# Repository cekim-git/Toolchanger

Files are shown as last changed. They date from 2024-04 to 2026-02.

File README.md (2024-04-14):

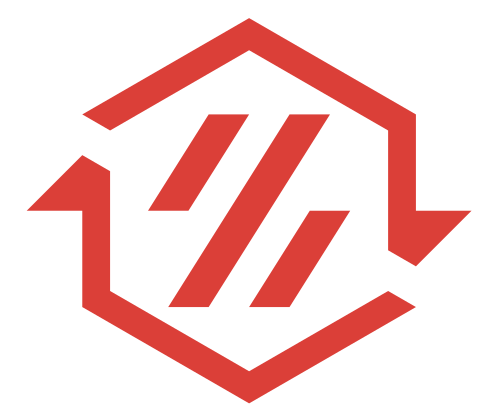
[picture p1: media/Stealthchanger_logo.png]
#  StealthChanger
**Tool changing system for Vorons and other front mount printer motion systems.**

## Introduction

Unlike the name suggests we support more then just stealthburner.

Due to difficulties with heat insert and aligning of bearings and mounts we wanted to try a more simplistic design based on bushings and pins.

This is a very light design, requiring less parts and as such is cheaper and easier to build.  Input shaper tests have shown it to be as rigid if not more than current Tapchanger.

All parts are easily replaceable without reprinting if wear happens, life of the bushings and pins are still being tested.

## Tool compatability
Currently we support the standard Stealth Burner, Dragon Burner, and Rapid Burner.  There are plans in place to add the Mini Stealth Burner, XOL, and Archetype.

## Documentation and Info

Please use our [wiki](../../wiki) for more information and documentation.

- [Bill of Materials](../../wiki/Bill-of-Materials)
- [Printing](../../wiki/Printing)
- [Assembling](../../wiki/Assembling)
- [Installation](../../wiki/Installation)
- [Configuration](../../wiki/Configuration)
- [Docks](../../wiki/Docks)
- [Slicers](../../wiki/Slicers)
- [Support and FAQs](../../wiki/Support-and-FAQs)
- [Contributing](../../wiki/Contributing)
- [Contributors & Credits](../../wiki/Contributors-and-Credits)

## Preview
### Printed Parts (Dragonburner) by BT123


### Important! - Check for clear Hex's (Dragonburner) by BT123
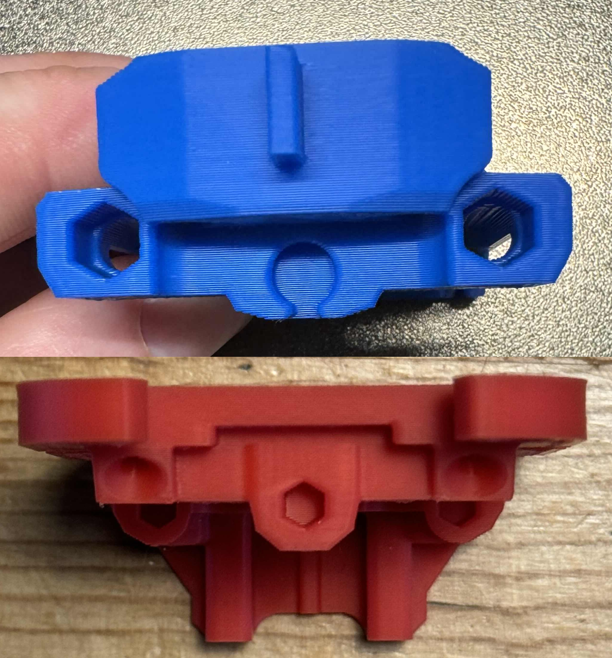
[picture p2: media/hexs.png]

### Assembled Shuttle and Backplate by BT123

### Motion (Stealthburner) by TheSin-

### Docking (Stealthburner) by fiferboy


Originally based on Viesturz's [Tapchanger](https://github.com/viesturz/tapchanger)

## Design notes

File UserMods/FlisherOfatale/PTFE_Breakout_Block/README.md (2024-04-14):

# PTFE Breakout Block

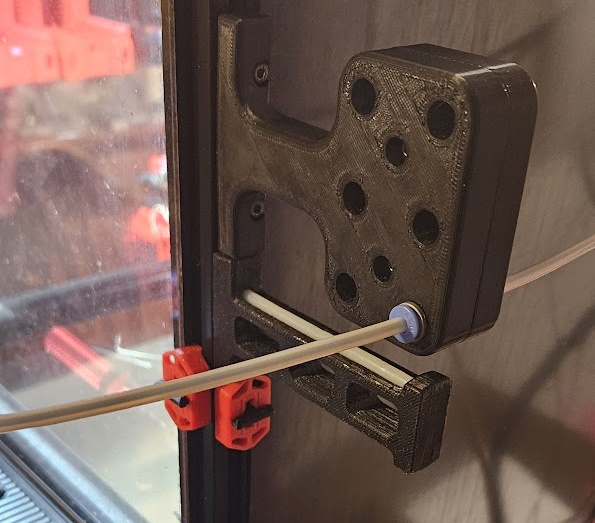
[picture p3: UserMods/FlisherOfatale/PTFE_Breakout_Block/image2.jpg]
PTFE Breakout Block


## What is it?
I designed the Breakout Block with the following idea in mind:
* Similar "lenght" than the stock Voron Spool Holder so it maintain existing clearance for people using the original setup
* Provide some constrain to the PTFE so it doesn't king when using 3mm innder diameter
* use ECAS because they are practical for this purpose
* Optional, seconary part that serve as a breakout block, allowing to "detach" easily both side of the block to decouple the toolhead and the spool holder when doing printer maintenance

## Special Notes
The design is probably not perfect but it was good enought for me at this point.

## Files
* [Main part v3.1](Flisher-PTFE_Breakout_Block_Main-v3.1.stl)
* [Secondary Part v3.1](Flisher-PTFE_Breakout_Block_Secondary-v3.1.stl)
* [Step File](Flisher-Toolchanger-PTFE-Holder-v3.1.STEP)

## BOM
* 2x M3 T-Nuts or Roll-in Nuts
* 2x M3x12 SHCS Screws 
* 1x ECAS Connector per Lane you want activate

If using both parts
* 2x M3x16 SHCS Screws (Voron Sandard)
* 2x M3 heat insert (Voron Sandard)
* Additional 1x ECAS Connector per Lane you want activate (ie: 12 totals if using 6 toolheads)

## Instructions
### Main Part
* Validate that your PTFE can go trought easily, if not, you might have to deburr rthe side facing the bed.
* Install the ECAS connectors
* Screw to the back of the printer using M3 T-Nuts and M3x12 SHCS Screws

You can stop here if you only wanted something to constrain the filament path and use it as a passtrought

### Secondary part
* Validate that your PTFE can go trought easily, if not, you might have to deburr rthe side facing the bed.
* Install the ECAS connectors
* Install the 2 heats inserts (on the same side than the ECAS connector)
* Install on the main block by using 2x M3x16 SHCS Screws
* Push the PTFE coming from the main part as it can get 2mm inside 
* Attach the PTFE from the printer side
  
You now have a setup you can decouple by pulling the filament back to the spool holders and unscrewing the block.

### Additional Pictures
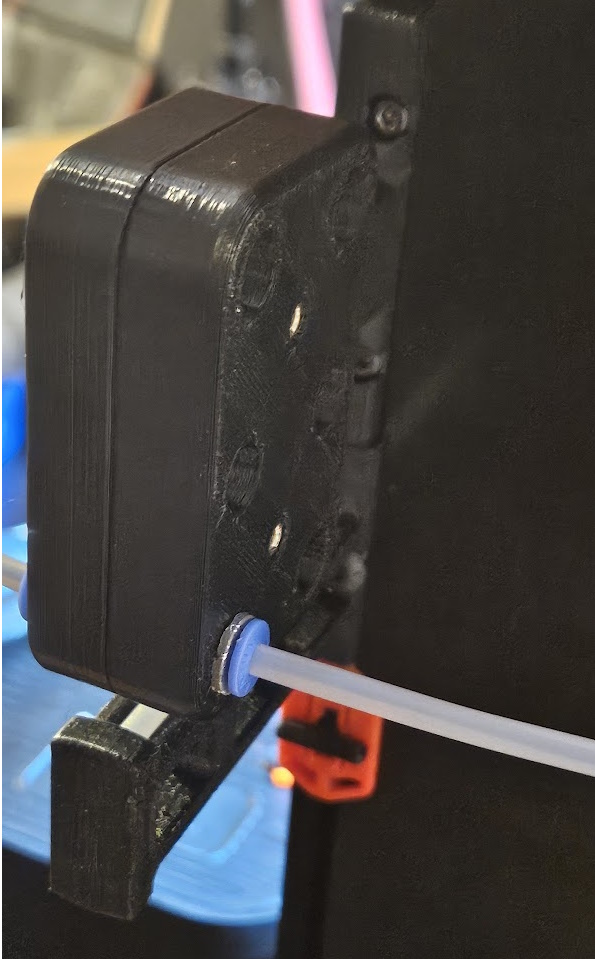
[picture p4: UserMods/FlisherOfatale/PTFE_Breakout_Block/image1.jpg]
Secondary Partg


## Changelog
* V3.1 2024-03-24 - Initial Release, each parts are 12mm wide

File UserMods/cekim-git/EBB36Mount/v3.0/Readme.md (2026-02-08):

## Dragon Burner EBB36 mount for the Orbiter2.x extruder
This mount for DragonBurner provides a mount for the EBB36 that attaches to the rear of the Orbiter2.x and provides a pivoting strain-relief tower intended to be used with a 1mm piano wire.

## Design Goals:
- As with prior versions, provided centered EBB36 mount (offset from extruder motor) and provide clearance for optTap sensor
- Move cable mount to pivoting tower as close to the front as possible to line up with the filament tube
- Optional heatset in the wire strain-relief tower to permit bung-screw to clamp the piano wire
- Does not integrate with the filament sensor, optimizing for umbilical/PTFE alignment/movement

## BOM:
- 3x m3 (x4x5) heatset-inserts in EBB36 mount holes 
- 2 m3x8 SHCS or BHCS (EBB36 mount)
- 1 m3x20 SHCS (pivot mount)
- (optional) 1x m3x4x5 heatset-insert for wire-tower clamp
- (optional) 1x m3x4 cup-point set-screw (bung screw)

## Printing:
- I print this standing upright with supports on overhanging elements
- ABS with shrinkage compensation - ensure you are printing with accurate dimensionality of finished part

## Installation:
- Install heatsets to EBB36 mounting face.
- Remove the 2 m3x16 SHCS holding the stepper motor of the Orbiter2.0 to the gearbox taking care to keep the gearbox assembled while the screws are removed.
- Replace stock gear-box screws with m3x25 screws
- While keeping the stepper motor, optional sensor and gearbox assembly together, slide the rear of the stepper into the mount's cup that is sized to fit around it. 
- Line up the screw-holes on the fingers with the Orbiter's stepper motor fastener holes.
- While pressing this entire assembly together, thread in the m3x25 screws.  You are simultaneously fastening the Orbiter2.x stepper to its gear-box and self-tapping the 3mm ABS holes on the mounting bracket, so keep them pressed together the entire time.
- Install EBB36 with 2 m3x8 SHCS or BHCS to the rear.
- If using the "piano-wire" hole, you may want to insert your 1mm wire prior to assembly to clear out any printing artifacts.  It is a ~18-20mm deep hole.
- If using the clamping wire-tower, press the heat-set insert into the tower
- Fasten the piano wire with teh m3x4 bung/set screw
- Wire as needed.





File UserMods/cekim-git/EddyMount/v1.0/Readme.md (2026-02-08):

## Eddy Coil Mount in a DragonBurner Tool-head
This design places the EddyCoil PCB in the spacer of the Dragon Burner toolhead

Dragonburner orignal design chirpy2605 here https://github.com/chirpy2605/voron

## Design Goals:
- Integrate EddyCoil into dockable toolhead

This uses "standard" DragaonBurner cowls

## BOM:
- (optional) aluminum tape (insullation)
- (optional) catridge PT1000 sensor

## Printing:
- Print in normal orientation for spacer
- Use supports for inner segments of both the spacer and front cover

## Installation:
- Insert PT1000
- Remove Eddy from its housing (carefully)
- Insert Eddy into printed spacer
- Place front cover
- Install spacer as normal from here




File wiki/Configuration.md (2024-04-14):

Toolchangers start with number 0, and count up. So for all the configs, make sure you change all sections. IE, in your T1 config, make sure its extruder1, fan1, etc. See the examples.  **NOTE: The only except to this rule is T0 extruder has no number.**

1. [Toolhead Configuration](#toolheads-configuration)
2. [CANbus](#canbus)
3. [Offsets](#offsets)

## Toolheads Configuration

Please see the repo files for more info on these. [Configuration Files Repo](https://github.com/DraftShift/StealthChanger/blob/main/Klipper)
[testing](/blob/main/Klipper)

You need to add the info in printer.cfg from the repo to your your printer.cfg
You need to have a separate toolhead config for each toolhead, then link those in your printer.cfg, as well as removing/moving the current extruder/hotend config from your printer.cfg file. See the examples in the repo for more information and a starting place. You will have to edit them with your own values.

## CANbus

[Esoterical CANbus](https://github.com/Esoterical/voron_canbus) this is a pretty definitive guide for canbus implementation on klipper.

**Example CANbus layout**

Example CANbus Layout

## Offsets

There are 2 places to set offsets in your toolhead config files. There is gcode_(x/y/z)_offset in the [tool] section, and (x/y/z)_offset in the [tool_probe] section. These do different things. The ones in the [tool] section are always relative to a specific tool. IE, if you homed with T0, then the gcode offsets are relative to T0. When you do multi-material prints, you will have to choose 1 tool to always do the homing, even if you don't use it, because all the other offsets need to be set against it. The [tool_probe] offset is only ever applied when homing with that tool. The gcode offsets are applied when changing a tool.

You should set all the [tool_probe] offsets as well though. If you are only using a single tool, you can home with that tool, and it will use the offset in the [tool_probe] section. You won't need to home with your primary tool first then before you start a print. 

To try and further clarify. Lets say you have 3 tools, T0, T1, and T2. We will say that T0 is your "primary" tool. Setup the probe z_offset like you would any other printer. Make sure the offset is set in z_offset (IE, make sure when you home and go to Z0, the nozzle is actually in that spot). Its location in x/y/z is always going to be 0 in relation to the other tools. So after T0 is homed, T1 and T2 (may) need to have their gcode_(x/y/z)_offset changed so they match the location that the primary tool actually is. There are 2 main ways of doing this. You can use a test print to print layers on top of or next to each other (something like this: [Nozzle Alignment Assist](https://www.printables.com/model/109267-nozzle-alignment-assist)) or you can use a camera (something like [kTAMV Klipper Tool Alignment](https://github.com/TypQxQ/kTAMV) or [IDEX Nozzle Calibration Tool](https://github.com/Life0fBrian/Brians-IDEX-Nozzle-Calibration-tool)).

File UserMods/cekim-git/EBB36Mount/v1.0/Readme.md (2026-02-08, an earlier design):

## Dragon Burner EBB36 mount for the Orbiter2.0 extruder
This mount for DragonBurner provides a mount for the EBB36 that attaches to the rear of the Orbiter2.0. 

Dragonburner orignal design chirpy2605 here https://github.com/chirpy2605/voron

Traxman25's EBB36 mount takes a different approach and can be found here:
https://github.com/cekim-git/Toolchanger/tree/main/UserMods/traxman25/Dragonburner_EBB36_SC_Mount

## Design Goals:
- Keep the Orbiter 2.0 on the original/shorter exrtuder block, flush with the top of the cowl.
- Provide a CAN cable stress-relief tower with zip-tie holes that is shifted to be in-line with the filament tube for cable harness alignment.
- Provide clearance for the opto-tap PCB without adding over-all height or extending rearward (the EBB36 and OptoTap will be roughly in-line with eachother).
- Remove the need for stand-offs and potentially add rigidity by augmenting the attachment screws with design features fit to the outside of the Orbiter2 stepper motor.
- Support the optional Orbiter2.0 filament sensor via the mount with shorter fingers.
- Provide hole on cable stress-relief tower to insert 1mm "piano-wire" to support the umbilical

This uses "standard" DragaonBurner cowls - though it is specifically fit for Traxman25's numbered cowls for StealthChanger, it will also fit on a standard cowl.  It also works the V1 back-plate for StealthChanger/DragonBurner and OptoTap.

## BOM:
- 2 m3 (x4x5) heatset-inserts mounted from the opposite side as the EBB36 
- 2 m3x8 BHCS (EBB36 mount)
- (no filament sensor) 2 m3x20 SHCS to replace the Orbiter's stock screws and provide more thread purchase in the ABS.
- (filament sensor) 2 m3x25 SHCS to replace the Orbiter's stock screws

## Printing:
- I print this standing upright as it sits in the machine with organic/tree supports painted on to the most obvious overhangs.
- I use ABS with no adjustmnet for shrinkage from the design files as provided.

## Installation:
- Install heatsets to side opposite the EBB36 mounting face.  Ensure they are straight and the screw-path clear of overmelt after installation
- Remove the 2 m3x16 SHCS holding the stepper motor of the Orbiter2.0 to the gearbox taking care to keep the gearbox assembled while the screws are removed.
- Replace stock gear-box screws with m3x20 screws (or m3x25 if attaching the filament sensor).
- (optional) install the filament sensor to the Orbiter2.0.
- While keeping the stepper motor, optional sensor and gearbox assembly together, slide the rear of the stepper into the mount's cup that is sized to fit around it. 
- Line up the screw-holes on the fingers with the Orbiter's stepper motor fastener holes.
- While pressing this entire assembly together, thread in the m3x20 (or m3x25) screws.  You are simultaneously fastening the Orbiter2.0 stepper to its gear-box and self-tapping the 3mm ABS holes on the mounting bracket, so keep them pressed together the entire time.
- Install EBB36 with 2 m3x8 BHCS to the rear.
- If using the "piano-wire" hole, you may want to insert your 1mm wire prior to assembly to clear out any printing artifacts.  It is a 20mm deep hole.
- Wire as needed.





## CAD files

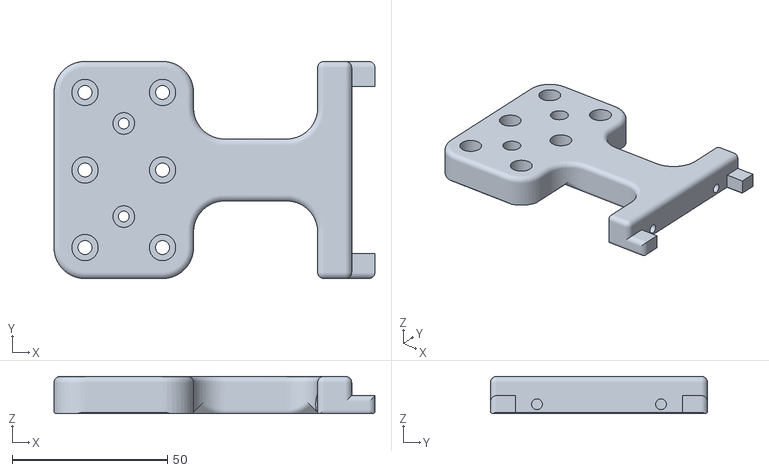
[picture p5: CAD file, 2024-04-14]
UserMods/FlisherOfatale/PTFE_Breakout_Block/Flisher-PTFE_Breakout_Block_Main-v3.1.stl
103.5 x 70.0 x 12.0

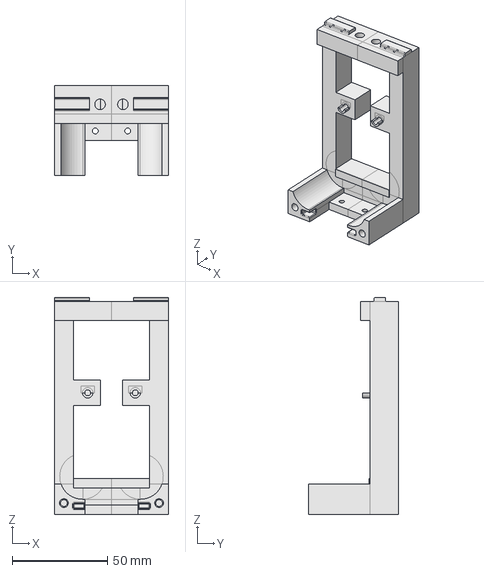
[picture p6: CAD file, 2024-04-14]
UserMods/cekim/DB_Dock/v0/DB_Dock.step
60.0 x 47.5 x 114.0 mm

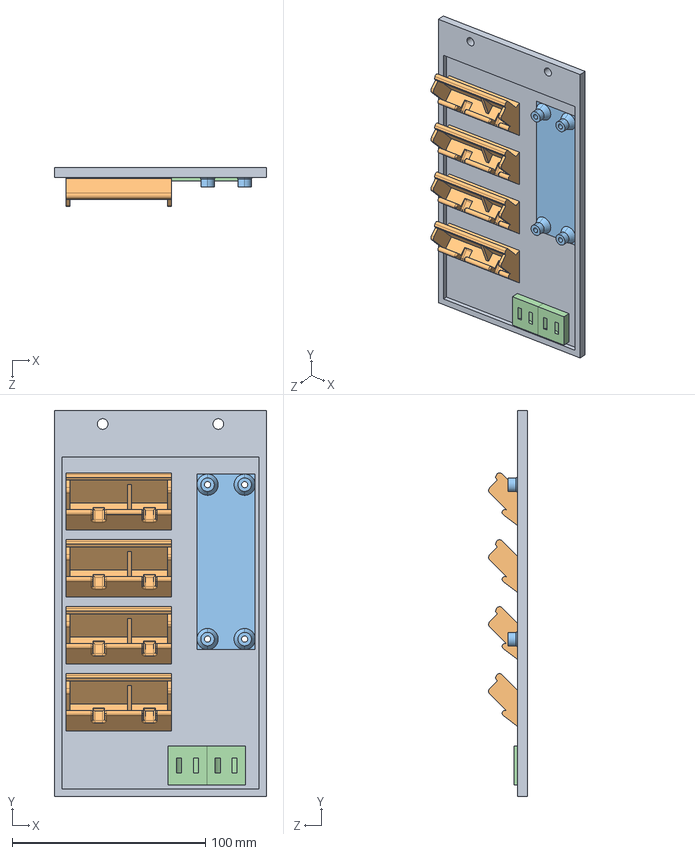
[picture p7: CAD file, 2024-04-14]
UserMods/FlisherOfatale/Temporary_Backplate/Flisher-Temporary_Backplate-V2.STEP
110.0 x 200.0 x 20.1 mm
Flisher-Backplate-v2-Naked
Stealchanger-Wago-5-3-Custom x 4
Stealchanger-BTT-U2C-SLDPRT
ZipTie-2020notch x 2

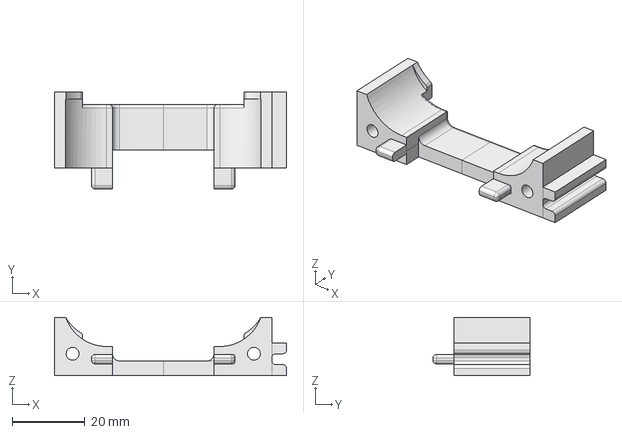
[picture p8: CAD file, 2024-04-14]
UserMods/cekim/DB_Dock/v0/DB_Dock_RearFemale.step
64.0 x 26.8 x 16.0 mm

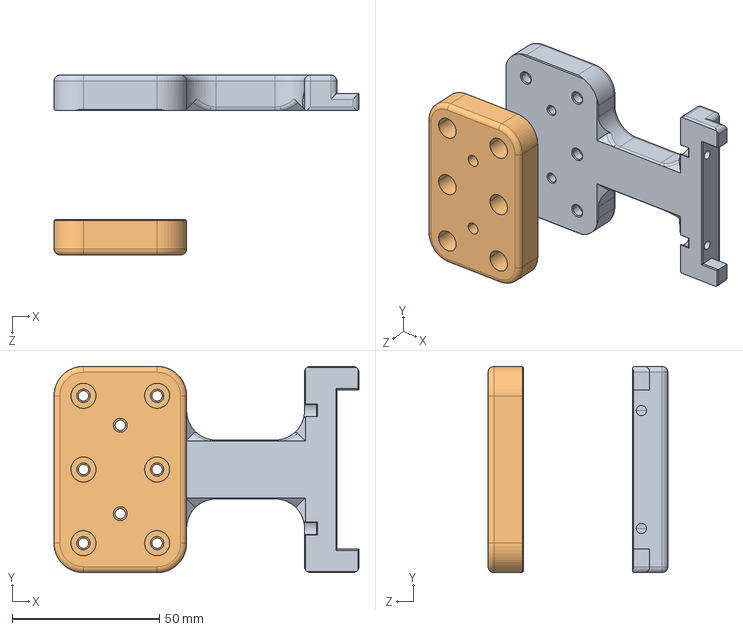
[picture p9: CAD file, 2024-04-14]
UserMods/FlisherOfatale/PTFE_Breakout_Block/Flisher-Toolchanger-PTFE-Holder-v3.1.STEP
103.5 x 70.0 x 61.0 mm

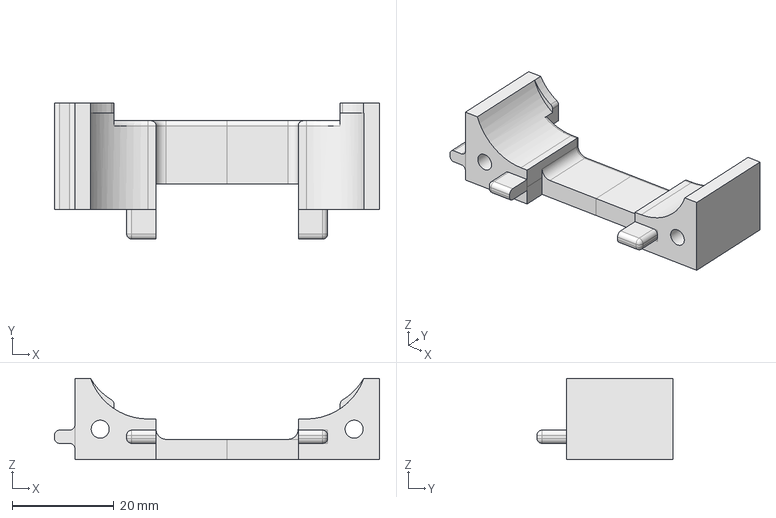
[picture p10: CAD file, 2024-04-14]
UserMods/cekim/DB_Dock/v0/DB_Dock_RearMale.step
64.0 x 26.8 x 16.0 mm

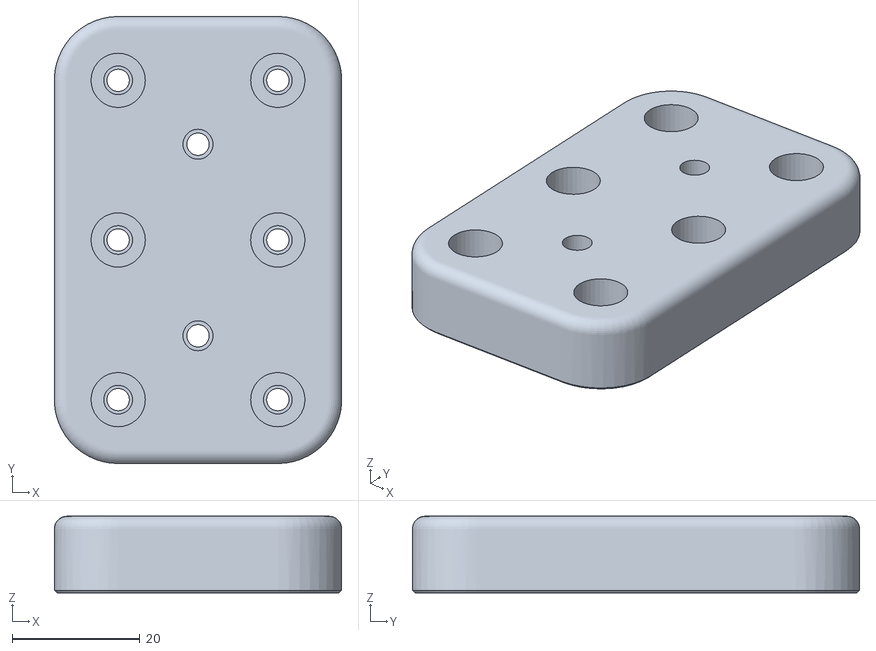
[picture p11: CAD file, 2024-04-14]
UserMods/FlisherOfatale/PTFE_Breakout_Block/Flisher-PTFE_Breakout_Block_Secondary-v3.1.stl
45.0 x 70.0 x 12.0

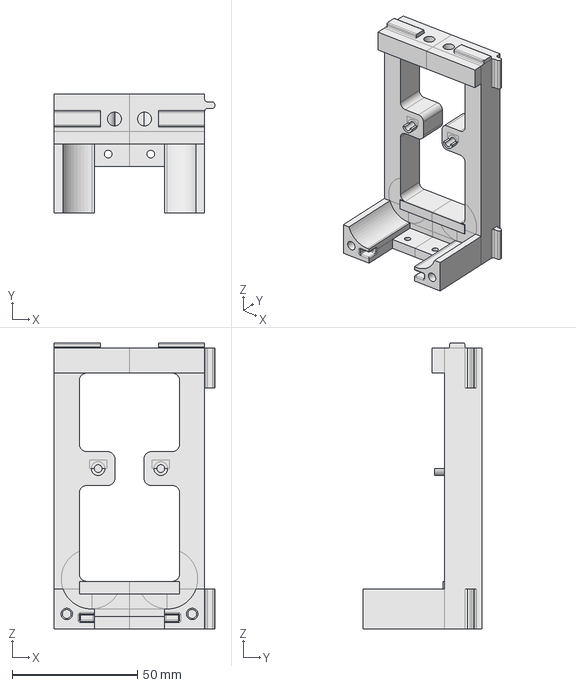
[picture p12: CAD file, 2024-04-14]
UserMods/cekim/DB_Dock/v0/DB_DockMale.step
64.0 x 47.5 x 114.0 mm

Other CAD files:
UserMods/cekim/DB_Dock/v0/DB_DockFemale.step
UserMods/FlisherOfatale/Temporary_Backplate/Flisher-Temporary_Backplate-V2.STL

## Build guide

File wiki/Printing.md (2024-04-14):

1. [Parts](#parts)
2. [Settings](#settings)
3. [Orientation](#orientation)

## Parts

**NOTE: The Dragonburner dock in the Tapchanger repo uses a custom cowl that is not compatible with or supported by Stealthchanger. Until a dock that is compatible with the original Dragonburner cowl is released, you must use the [custom cowl by OstroMa](https://github.com/DraftShift/StealthChanger/blob/main/UserMods/OstroMa/DB_Cowl_v8_with_TapChanger_Dock_Hooks.stl). We always recommend to use the original cowls when possible.**

Coming Soon

## Settings

All print settings are the same as [Voron Standards](https://docs.vorondesign.com/sourcing.html#print-settings) or better.

## Orientation

Print orientation is flat on the parts back with supports enabled currently, we are working on models with integrated supports.

Print Orientation

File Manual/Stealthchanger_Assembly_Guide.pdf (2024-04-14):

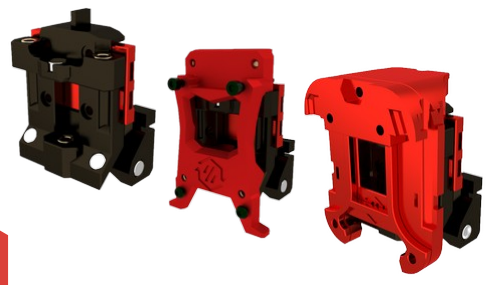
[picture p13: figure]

# STEALTHCHANGER V1 BUILD GUIDE

# Because you can never have too many tools

for any project.

# VERSION 2024-04-12

# DRAFTSHIFT DESIGN

PREFACE | GITHUB.COM/DRAFTSHIFT/STEALTHCHANGER

Before you begin on your journey, a word of caution.

In the comfort of your own home you are about to assemble a robot. This machine can maim, burn, and electrocute you if you are not careful. Please do not become the first STEALTHCHANGER fatality. There is no special Reddit flair for that.

Please, read the entire manual before you start assembly. As you begin wrenching, please check our Discord channels for any tips and questions that may halt your progress.

Most of all, good luck!

THE DRAFTSHIFT DESIGN TEAM

2

## TABLE OF CONTENTS

Introduction | 04
Hardware | 07
Shuttle | 08
Stealthburner | 11
Dragonburner | 14
Attaching to Carriage | 17
End Stop Options | 21
Next Steps | 22

3

## GITHUB.COM/DRAFTSHIFT/STEALTHCHANGER

## INTRODUCTION

PART PRINTING GUIDELINES

The Voron Team has provided the following print guidelines for you to follow in order to have the best chance at success with your parts. The StealthChanger Team recommends to follow the same standards. There are often questions about substituting materials or changing printing standards, but we recommend you follow these:

3D PRINTING PROCESS
Fused Deposition Modelling (FDM)

MATERIAL
ABS

LAYER HEIGHT
Recommended: 0.2mm

EXTRUSION WIDTH
Recommended: Forced 0.4mm

INFILL TYPE
Grid, Gyroid, Honeycomb, Triangle or Cubic

INFILL PERCENTAGE
Recommended: 40%

WALL COUNT
Recommended: 4

SOLID TOP/BOTTOM LAYERS
Recommended: 5

4

## INTRODUCTION

FILE NAMING

By this time you should have already downloaded our STL files from the StealthChanger GitHub. You might have noticed that we have used the Voron naming convention for the files. This is how to use them.

PRIMARY COLOUR

Example part_x4.stl

These files will have nothing at the start of the filename.

ACCENT COLOUR

Example [a]_part.stl

We have added “[a]” to the front of any STL file that is intended to be printed with accent colour.

QUANTITY REQUIRED

Example [a]_part_x4.stl

If any file ends with “_x#”, that is telling you the quantity of that part required to build the machine.

HOW TO GET HELP

If you need assistance with your build, we are here to help. Head on over to our Discord group and post your questions. This is our primary medium to help STEALTHCHANGER Users and we have a great community that can help you out if you get stuck.

### https://discord.gg/jJs73c6vSc

5

## INTRODUCTION

REPORTING ISSUES

Should you find an issue in the documentation or have a suggestion for an improvement please consider opening an issue on GitHub (https://github.com/DraftShift/Stealthchanger/issues). When raising an issue please include the relevant page numbers and a short description; annotated screenshots are also very welcome. We periodically update the manual based on the feedback we get.

THIS IS JUST A REFERENCE

This manual is designed to be a simple reference manual. Building a StealthChanger can be a complex endeavour and for that reason we recommend downloading the CAD files off our Github repository if there are sections you need clarification on. It can be sometimes be easier to follow along when you have the whole assembly in front of you.

### https://github.com/DraftShift/StealthChanger

6

## HARDWARE REFERENCE

BUTTON HEAD CAP SCREW (BHCS) Metric fastener with a domed shape head and hex drive. Most commonly found in locations where M5 fasteners are used. ISO 7380-1 | SOCKET HEAD CAP SCREW (SHCS) Metric fastener with a cylindrical head and hex drive. The most common fastener used on the Voron. ISO 4762
FLAT HEAD COUNTERSUNK SCREW (FHCS) Metric fastener with a cone shaped head and a flat top. ISO 10642 | HEAT SET INSERT Heat inserts with a soldering tip so that they melt the plastic when installed. As the plastic cools, it solidifies around the knurls and ridges on the insert for excellent resistance to both torque and pull-out.
BUSHING/SLEEVE BEARING Brass cindered are the most common. They should be self lubricating and metal construction. | ROUNDED DOWEL PIN Steel rounded dowel pin, These are commonly using in furniture construction. Female threaded versions are optional.

MAGNET Metric round button neodymium magnet used on the Voron. N52 is highly recommended.

7

## SHUTTLE

INSERT BUSHINGS

Inspect the bushing hex holes, make sure they are 6mm between walls of the hex. Make sure the hex is well formed. This is an important step as it could cause misalignment later on.

Apply a small amount of epoxy or glue to the inside of the hex (be sparing as you do not want any inside the the bushing).

Push the bushing into the hex and let sit until the epoxy or glue dries.

NOTE: Wipe any excess away and make sure none goes inside the bushing.

NOTE: you may be able to friction fit the bushings to test before your affix them permanently.

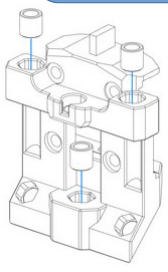
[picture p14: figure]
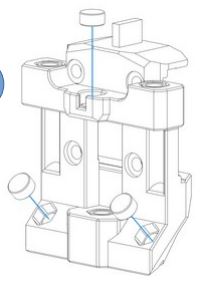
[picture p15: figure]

INSERT MAGNETS

Apply a small amount of epoxy or glue to the inside of the opening.

Push the magnet into the opening and let sit until the epoxy or glue dries.

NOTE: you may be able to fiction fit the magnets to test before your affix them permanently.

## 4 ID x 6 OD x 6mm Bushing

## 6x3mm Magnet

8

## SHUTTLE

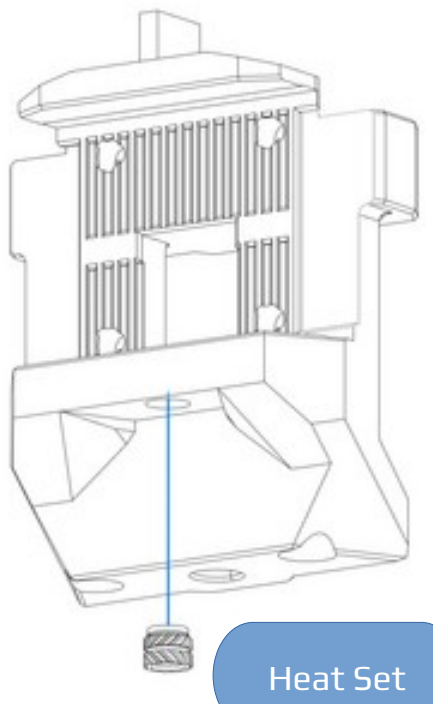
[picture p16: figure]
Heat Set

OPTIONAL INSERT HEAT SET

Optionally insert the end stop heat set. Only required if you are not using sensorless.

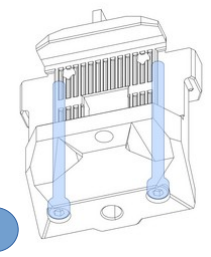
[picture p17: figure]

OPTIONAL SPINE SCREWS

Optionally screws can be inserted to add rigidity to the shuttle if your not happy with it’s stiffness

## M3x40mm SHCS

9

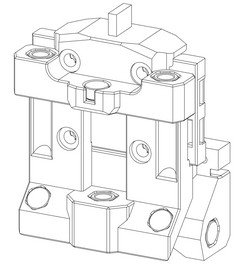
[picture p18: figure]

FINISHED SHUTTLE

This is the finished shuttle with options shuttle keeper (later in this manual) and the optional Hall Effect end stop attachment (later in this manual).

## SHUTTLE

10

## STEALTHBURNER

INSERT HEAT SETS

Start by setting the heat sets.

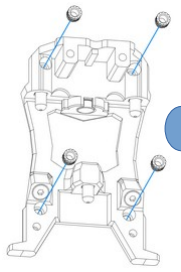
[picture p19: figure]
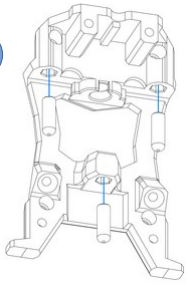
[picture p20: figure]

INSERT DOWEL PINS

Inspect the pin hex holes, make sure they are 4mm between walls of the hex. Make sure the hex is well formed. This is an important step as it could cause misalignment later on.

Apply a small amount of epoxy or glue to the inside of the hex.

Push the pins into the hex and let sit until the epoxy or glue dries.

NOTE: You may be able to friction fit the pins to test before your affix them permanently.

NOTE: You should test fit the pins onto the plate and the plate with the pins on the shuttle before making them permanent.

NOTE: Make sure to wipe away any excess so your can have a full sit into the bushings.

## Heat Set

## 4 OD x 12mm Pins

11

## STEALTHBURNER

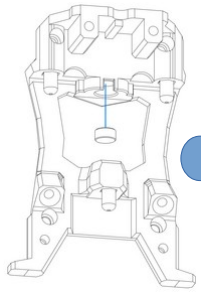
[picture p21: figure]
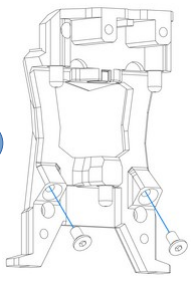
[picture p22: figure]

PRELOAD SCREWS

Insert the preload screws all the way, do not over tighten, we will set these later in this document (See Next Step). These just thread into the printed part without a heat set.

NOTE: These screws need to be magnetic like used in Voron Tap.

INSERT MAGNETS

Apply a small amount of epoxy or glue to the inside of the opening.

Push the magnet into the opening and let sit until the epoxy or glue dries.

NOTE: you should be able to fiction fit the magnets to test before you affix them permanently.

## 6x3mm Magnet

## M3x8mm FHCS

12

## STEALTHBURNER

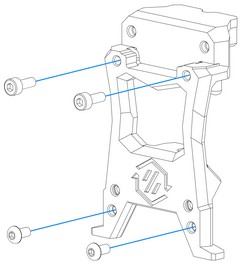
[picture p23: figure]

PREPARE FOR STEALTHBURNER

Install the screws to click on the stealthburner bottom piece. See stealthburner guild for screw sizes.

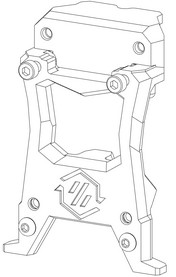
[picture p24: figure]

FINISHED TOOL PLATE

This is the finished stealthburner tool plate now continue with the official stealthburner guide from the Voron team.

NOTE: you may need to use longer screws when attaching the CW2.

13

## DRAGONBURNER

INSERT HEAT SETS

Start by setting the heat sets.

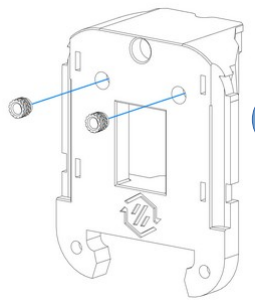
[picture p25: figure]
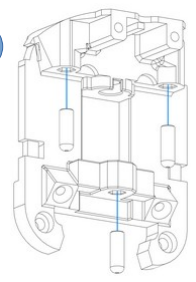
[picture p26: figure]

INSERT DOWEL PINS

Inspect the pin hex holes, make sure they are 4mm between walls of the hex. Make sure the hex is well formed. This is an important step as it could cause misalignment later on.

Apply a small amount of epoxy or glue to the inside of the hex.

Push the pins into the hex and let sit until the epoxy or glue dries.

NOTE: You may be able to friction fit the pins to test before your affix them permanently.

NOTE: You should test fit the pins onto the plate and the plate with the pins on the shuttle before making them permanent.

NOTE: Make sure to wipe away any excess so your can have a full sit into the bushings.

## HeatSet

## 4 OD x 12mm Pins

14

## DRAGONBURNER

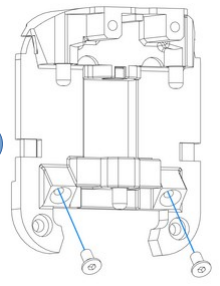
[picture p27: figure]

PRELOAD SCREWS

Insert the preload screws all the way, do not over tighten, we will set these later in this document (See Next Step). These just thread into the printed part without a heat set.

NOTE: These screws need to be magnetic like use in Voron Tap.

INSERT MAGNETS

Apply a small amount of epoxy or glue to the inside of the opening.

Push the magnet into the opening and let sit until the epoxy or glue dries.

NOTE: you should be able to fiction fit the magnets to test before you affix them permanently.

## 6x3mm Magnet

## M3x8mm FHCS

15

## DRAGONBURNER

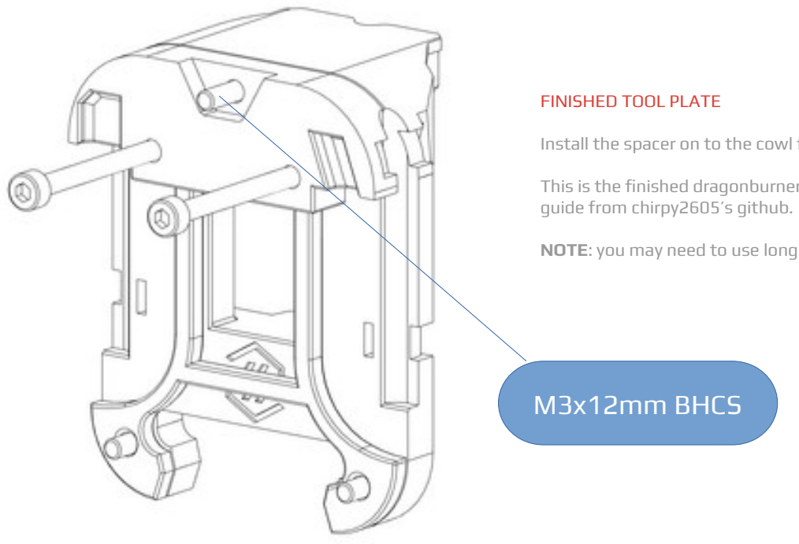
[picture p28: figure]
FINISHED TOOL PLATE; guide from chirpy2605’s github.; M3x12mm BHCS

Install the spacer on to the cowl first, then using the front cowl bolt add the backplate.

This is the finished dragonburner tool plate now continue with the official dragonburner

NOTE: you may need to use longer screws when attaching the cowl.

16

## ATTACHING TO CARRIAGE

SHUTTLE KEEPER

This is the easiest option, you loop the belts through the keeper, and then install it between the carriage and the shuttle using BHCS screws. You need longer screws to be able to go through both. Make sure you tighten the shuttle well.

Now adjust your belts as per standard Voron adjustments using the idlers.

OPTIONS

There are 2 options when it comes to attaching the belts and installing the shuttle to the X carriage.

1. You can use the shuttle keeper, this is the easiest way to install it the belts and allows for you to remove the shuttle without having to remove the belts. The down side is that you lose about 5mm of Y travel.
2. You can use the belt Helper tool to push the belts behind the shuttle and tighten the carriage screws which will pinch the belts between the carriage and the shuttle.

We will go though both options in this section but you only need to choose one.

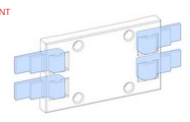
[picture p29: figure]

FRONT

BACK

INSTALL ORIENTATION

17

## ATTACHING TO CARRIAGE

BELT HELPER

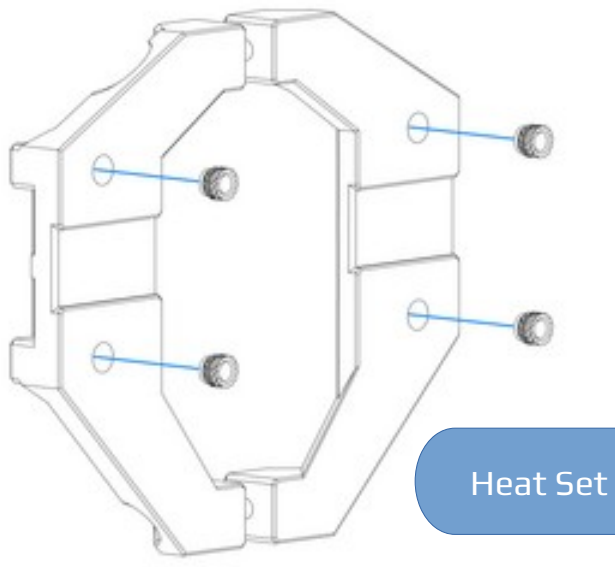
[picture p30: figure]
Heat Set

INSERT HEAT SETS

Start by setting the heat sets.

## Heat Set

18

## ATTACHING TO CARRIAGE

INSERT SCREWS

Add the belt clamps, make sure to match the icons with the right sides.

Install the belt clamp screws loosely.

Install the clamping screws loosely.

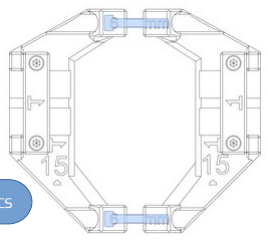
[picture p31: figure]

## M3x20mm SHCS

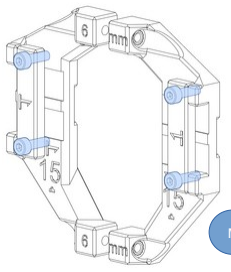
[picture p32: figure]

## M3x10mm SHCS

19

## ATTACHING TO CARRIAGE

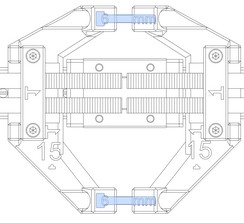
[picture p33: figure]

INSERT THE BELTS

Insert the belts, Making sure that there are 15 belt ridges on the inside of the helper. Makes sure you tighten the belt clamps well so the belt doesn’t slip.

NOTE: there is no need to pull hard the belts, just make sure there is no slack, if you pull too hard at this point you will over tighten the belts a could damage other components.

Next start to tighten the top and bottom screws, make sure your try to do this evenly until you measure 6mm between left and right side at the top and bottom evenly.

INSTALL THE SHUTTLE

NOTE: you must wait until after the shuttle is installed before adding any end stops if you are using one.

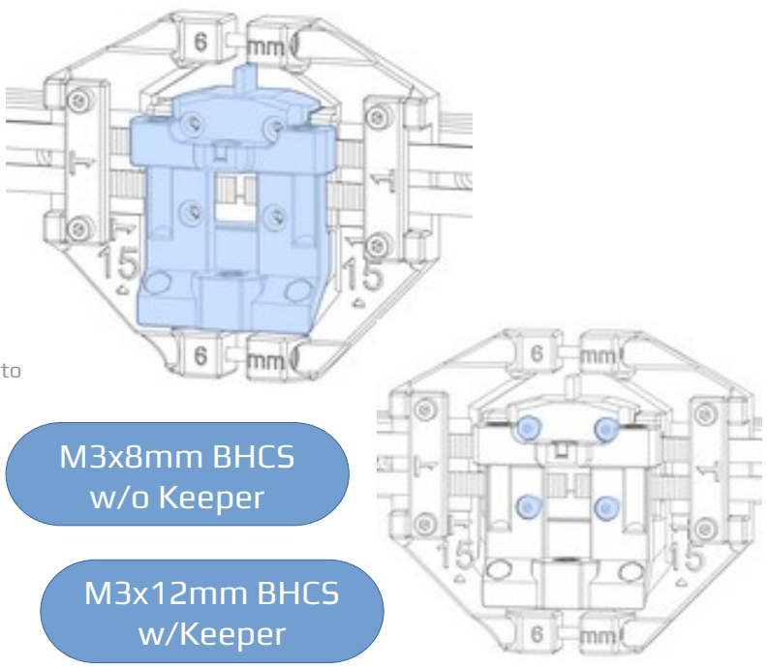
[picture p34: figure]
M3x8mm BHCS w/o Keeper; M3x12mm BHCS w/Keeper

The belt ends should be nearly touching, at this point install the shuttle and tighten it to the carriage using BHCS screws as per Voron Manual. Make sure things are nice and tight before you start to replace the helper.

Once you are ready, slowly undo the top and bottom screws evenly. Once there is enough slack you may remove the clamps on the belts and remove the helper.

Now adjust your belts as per standard Voron adjustments using the idlers.

20

## END STOP OPTIONS

OPTIONS

There are a few options when it comes to end stops. Hall Effect is a Voron stands as well as end stop switches. The team doesn’t provide the switch side, but we do have attachment points for and suppose to most common activation arms.

NOTE: more options may be available and are welcome.

HALL EFFECT
INSERT MAGNETS

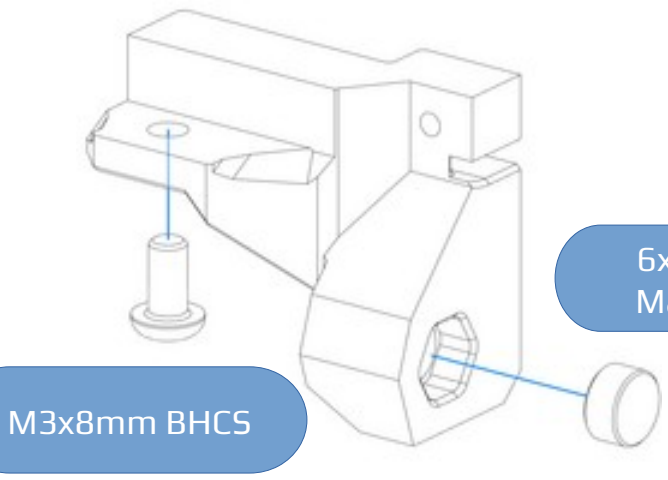
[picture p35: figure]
M3x8mm BHCS

Apply a small amount of epoxy or glue to the inside of the opening.

Push the magnet into the opening and let sit until the epoxy or glue dries.

NOTE: you should be able to fiction fit the magnets to test before you affix them permanently.

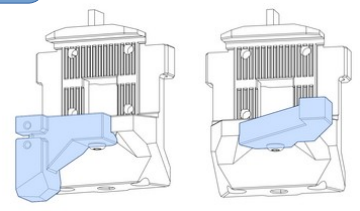
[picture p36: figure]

INSTALL THE END STOP ACTIVATION ARM

Simply screw it into the back side of the shuttle.

NOTE: Hall Effect and X Switch pictured.

## 6x3mm Magnet

21

## NEXT STEPS

ASSEMBLY COMPLETED!

The last step is to set preload. This should be done on each tool separately as it’s meant to help counter inconsistencies/variances in the parts.

Preload is created with the 2 countersunk screws in the tool plate. These 2 screws need to be magnetic and will make contact with the magnets in the shuttle. This adds 2 more wider points of contact at the base while also pre loading the sleeves/bearings. To adjust them screw them all the way in, then slowly unscrew them 1/4 turn at a time (keeping each side even) until the tool no longer engages its self right away. Once you reach a point where this happens, screw them back in 1/4 turn. Each tool needs to be adjusted separately as printing irregularities can happen and this will allow you to compensate for it. You may want to test and readjust these from time to time.

### https://github.com/DraftShift/Stealthchanger/wiki/Installation

22

NEXT STEP: SETUP & CALIBRATION

This manual is designed to be a reference manual for the build process of a StealthChanger.

The software setup and other initial setup steps with your new toolchanger can also be found on our github page. We recommend starting there.

Enjoy your toolchanger.

23

GITHUB

github.com/DraftShift

DISCORD

discord.gg/jJs73c6vSc

# DRAFTSHIFT DESIGN
